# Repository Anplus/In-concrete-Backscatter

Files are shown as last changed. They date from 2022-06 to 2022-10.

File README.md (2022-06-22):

# In-concrete Backscatter

We present a novel promising self-sensing concrete by introducing a novel functional filler, called EcoCapsule – a battery-free and miniature piezoelectric backscatter node. With the help of EcoCapsules, we can construct a battery-free sensing network inside the concrete building so that to achieve the persistent structural health monitoring.

# Content

PCB/ - the circuit design of EcoCapsule node

MCU/ - the MCU code of EcoCapsule node

Mechanical/ - the solidwork design file of the shell of the EcoCapsule node 

Reader/ - the Matlab code for transmitting FSK downlink command and decoding the uplink backscatter signals

# Acknowledgement

**Advisor/PI:** Lei Yang.

**For in-depth information on how PAB works:** 

[Website](https://web.comp.polyu.edu.hk/csyanglei/#/pages/profile/about)

This work is licensed under a MIT license.

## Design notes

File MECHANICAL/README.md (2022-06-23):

# Mechanical Design

This part includes the solidwork 3D design files for the shell of the Ecocapsule nodes and the Helmholtz resonance array (HRA). The node shells and HRAs are further 3D printed.

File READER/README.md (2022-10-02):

# Reader

We prototype the reader by using a multifunctional data acquisition board (DAQ) USB-3213 from Smacq. The DAQ transmits the 200 kHz signal to power up and send command to the tag. It also collects and decodes the uplink backscatter signal. The code is tested on MATLAB 2021a.

# How to run?

- Install the driver by installing the gusb.inf.
- Run the decoder.m.

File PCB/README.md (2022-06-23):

# PCB Design

This part includes the PCB design files for the circuit board of the Ecocapsule nodes. The board is a 35mm radius circle.

/simu-power.ms14 - The simulation file for the rectifier and power management.

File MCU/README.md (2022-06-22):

# MCU

This part includes the logic codes running on the core chip MSP430G2553. 

test/ - the testing code for evaluating the backscatter function

ADC/ - the ADC sampling function and then send back through acoustic backscattering

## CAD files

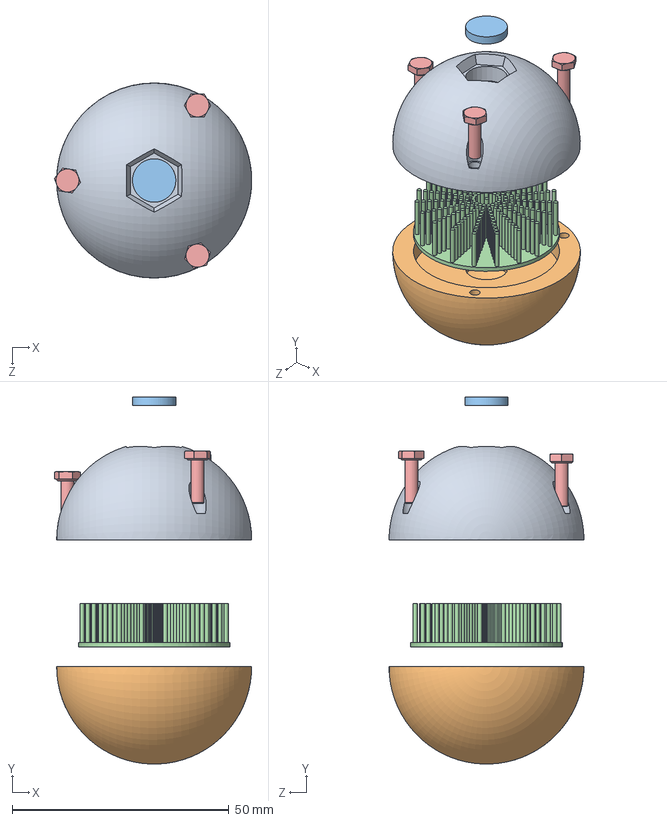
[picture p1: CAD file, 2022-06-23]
MECHANICAL/EcoCapsule_Shell/装配体1.SLDASM
45.5 x 84.7 x 45.0 mm
零件1
实体2
零件2
零件3
hexagon head bolts-full thread gb x 3

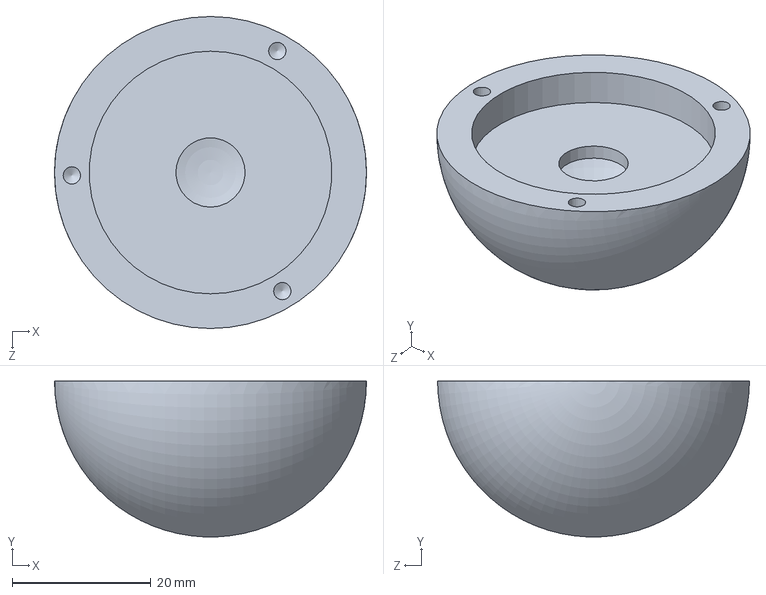
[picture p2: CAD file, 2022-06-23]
MECHANICAL/EcoCapsule_Shell/实体2.sldprt
45.0 x 22.5 x 45.0 mm

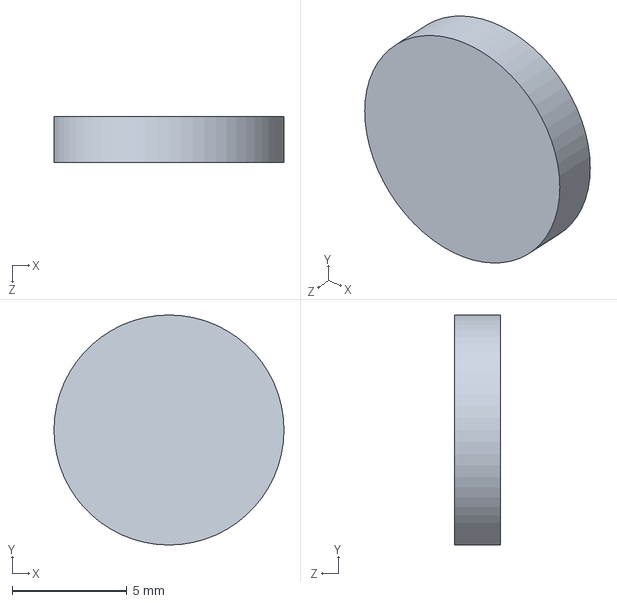
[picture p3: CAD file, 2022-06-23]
MECHANICAL/EcoCapsule_Shell/零件2.SLDPRT
10.0 x 10.0 x 2.00 mm

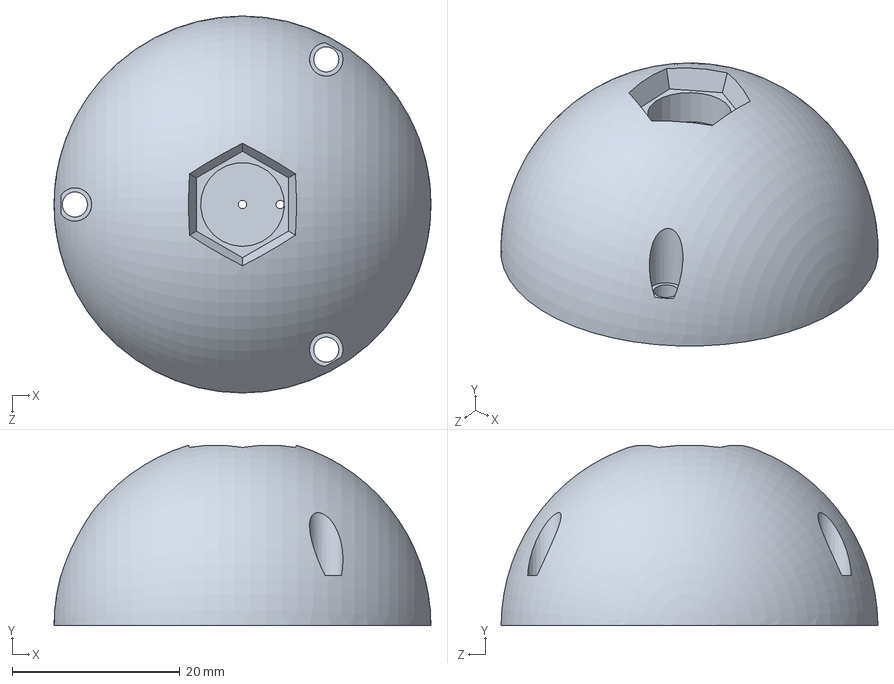
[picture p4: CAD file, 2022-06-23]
MECHANICAL/EcoCapsule_Shell/零件1.SLDPRT
45.0 x 21.5 x 45.0 mm

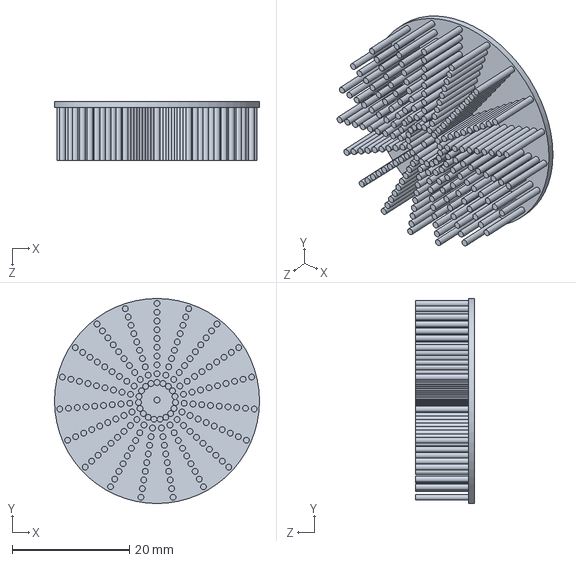
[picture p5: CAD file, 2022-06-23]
MECHANICAL/EcoCapsule_Shell/零件3.SLDPRT
35.0 x 35.0 x 10.0 mm

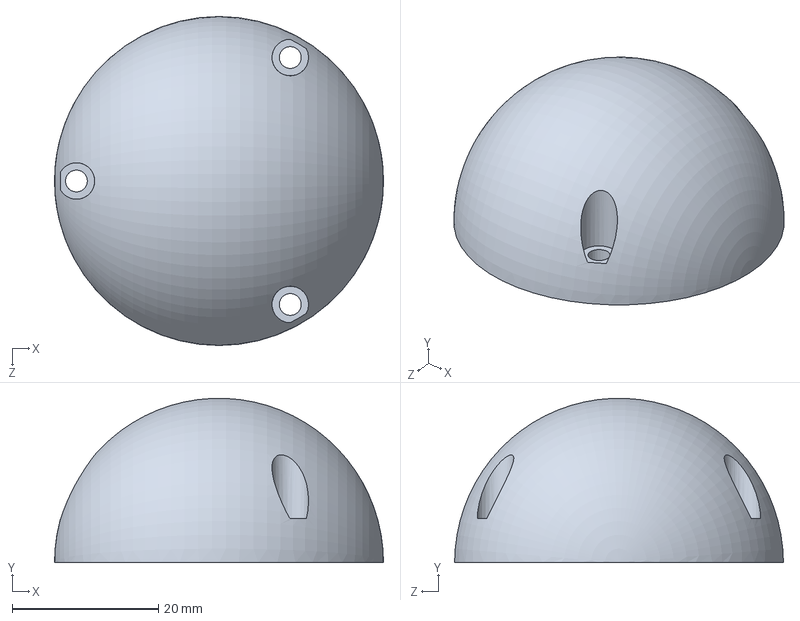
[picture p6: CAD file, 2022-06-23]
MECHANICAL/EcoCapsule_Shell/实体1.sldprt
45.0 x 22.5 x 45.0 mm

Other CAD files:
MECHANICAL/HRA/HRA June 15V1.STL

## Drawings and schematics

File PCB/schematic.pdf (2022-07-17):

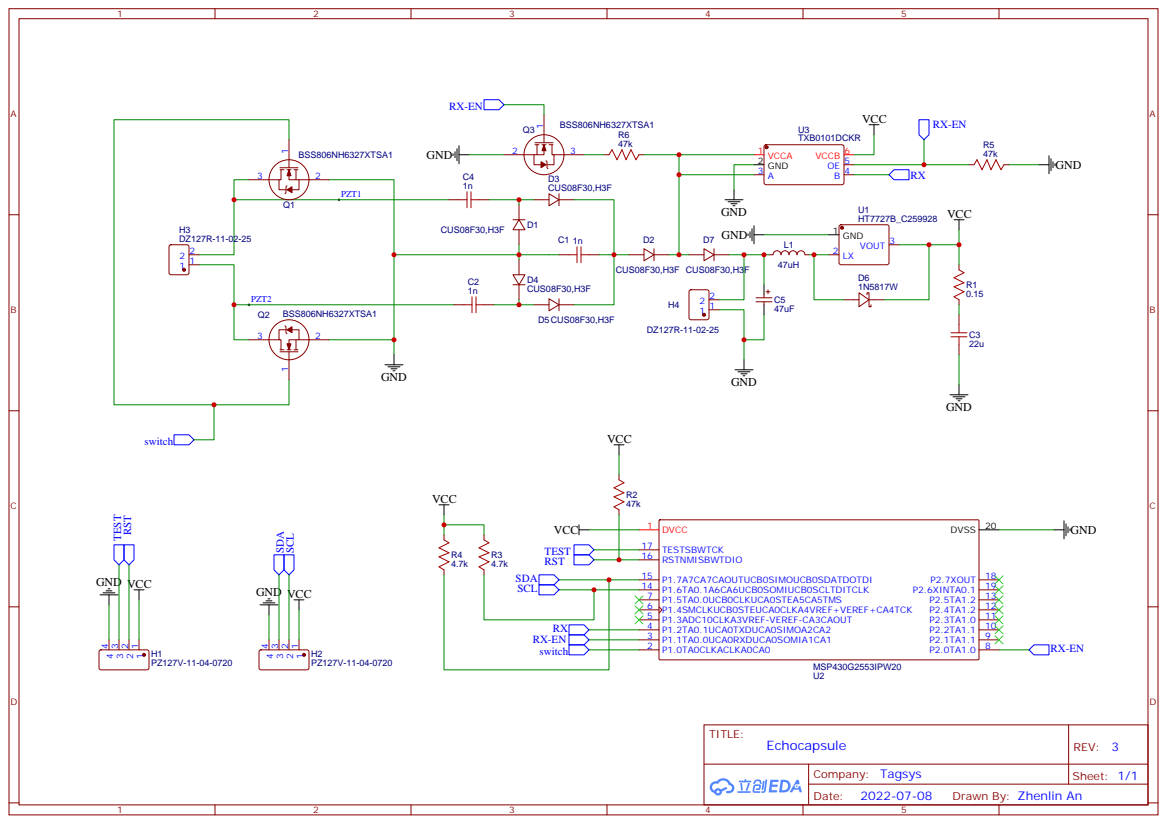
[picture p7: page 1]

GND VCC TEST RST

Drawn By: Zhenlin An

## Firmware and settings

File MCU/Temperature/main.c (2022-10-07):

#include <msp430.h>
#include "mpu6050.h"

int Temp;         //温度数据,单位摄氏度,该温度为芯片温度非环境温度

const int second_counter_max = 50;       //该值为n,则n ms采样转换一次.     修改此值即可修改采样率
int second_counter = 0;
const int numbit = 16;
int state = 0;
int already_sent = 0;
const int len = 50;
void send_data(){
    int data = Temp;
    int i = numbit-1;
    for(;i>=0;i--){
        if(state == 0){
            P1OUT |= BIT0; // swtich to high
            state = 1;
            __delay_cycles(50);
            if((data >> i) & 1U){
            // last 1 , --
                state = 1;
                //P1OUT |= BIT0;
            }else{
            // last 0, -_
                state = 0;
                P1OUT &= ~BIT0; // low
            }
        }else{
            P1OUT &= ~BIT0; // swtich to low
            state = 0;
            __delay_cycles(50);
            if((data >> i) & 1U){
            // last 1 , __
                state = 0;
                // P1OUT &= ~BIT0;
            }else{
            // last 0, _-
                state = 1;
                P1OUT |= BIT0; // high
            }
        }
        __delay_cycles(50);
    }
    state = 0;  // clear state
    P1OUT &= ~BIT0; // clear pin
}

// 50ms interrupt
#pragma vector=TIMER0_A0_VECTOR
__interrupt void Timer_A(void)
{
    // 50ms
    second_counter += 1;
    if(second_counter >= second_counter_max){
        second_counter = 0;
        Temp = MPU6050_GetData(TEMP_OUT_H);        //读取温度
        // start send data
        send_data();
    }
}

void TimerInit()
{
    BCSCTL1 = CALBC1_1MHZ; // Basic Clock System Control 1
    DCOCTL = CALDCO_1MHZ; // DCO Clock Frequency Control
    BCSCTL2 |=SELM_1+DIVM_1; // Basic Clock System Control 2, MCLK Source Select 1: DCOCLK, MCLK Divider 1: /2
    // timer 0 controlling the packet gap
    TACCR0 =  125; // 1 ms
    TACTL |= TASSEL_2 + ID_3 + MC_1; // SMCLK, ID_0: 1 divide, Up to CCR0
    //TACCR0 = 10e3; // 500Hz: 10e3, 1k:5e3, 2k: 2.5e3
    //TACTL |= TASSEL_2 + ID_0 + MC_1; // SMCLK, ID_0: 1 divide, Up to CCR0
    TACCTL0 |= CCIE;
}

/**
 * main.c
 */
int main(void)
{
    WDTCTL = WDTPW | WDTHOLD;   // stop watchdog timer
    MPU6050_Init();
    TimerInit();
    //ADC_init();
    P1DIR |= 0x01;   // Set P1.0 to output direction
    _BIS_SR(GIE);
}

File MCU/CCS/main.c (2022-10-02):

#include <msp430.h>
// continue send 01 data at different date rate and measure the power consumption
void backscatter_init()
{
  //P1.0 as backscatter control output
  P1DIR |= BIT0; // output
  P1OUT &= ~BIT0; // low
}

void TimerInit()
{
    BCSCTL1 = CALBC1_1MHZ; // Basic Clock System Control 1
    DCOCTL = CALDCO_1MHZ; // DCO Clock Frequency Control
    BCSCTL2 |=SELM_1+DIVM_0; // Basic Clock System Control 2, MCLK Source Select 1: DCOCLK, MCLK Divider 1: /2
    // timer 0 controlling the data rate
    // 500Hz:125, 1k:63, 2k:32, 3k:21, 4k:16, 5k:10, 6k: 9, 7k: 8, 8k: 7, 10k: 6
    TACCR0 = 6; // 50 ms
    TACTL |= TASSEL_2 + ID_3 + MC_1; // SMCLK, ID_0: 1 divide, Up to CCR0
    //TACCR0 = 10e3; // 500Hz: 10e3, 1k:5e3, 2k: 2.5e3
    //TACTL |= TASSEL_2 + ID_0 + MC_1; // SMCLK, ID_0: 1 divide, Up to CCR0
    TACCTL0 |= CCIE;
}

#pragma vector=TIMER0_A0_VECTOR
__interrupt void Timer_A(void)
{
    P1OUT^=(1<<0);
}

int main()
 {
   // Write your code here
   WDTCTL = WDTPW | WDTHOLD;    // stop watchdog timer
   backscatter_init();
   TimerInit();
   _BIS_SR(GIE);
   // LPM3; //enter the low-power mode 2
    return 0;
 }

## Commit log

2022-06-23 add pcb simulation
2022-10-02 update PCB and add reader
